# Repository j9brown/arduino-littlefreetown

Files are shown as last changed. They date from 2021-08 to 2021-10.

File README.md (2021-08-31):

# arduino-littlefreetown

Lighting controller for a two story combination Little Free Museum
and Little Free Library structure.

## Parts

PJRC Teensy 3.2 microcontroller
- https://www.pjrc.com/store/teensy32.html

FYSETC v2.1 LCD panel
- https://wiki.fysetc.com/Mini12864_Panel/
- https://github.com/FYSETC/FYSETC-Mini-12864-Panel
- https://www.amazon.com/FYSETC-Controller-Supports-Accessories-RGB-Backlight/dp/B08R9ZH7S2/

Adafruit bq24074 solar charger
- https://www.adafruit.com/product/4755

Adafruit 6 Volt 2 Watt solar panel

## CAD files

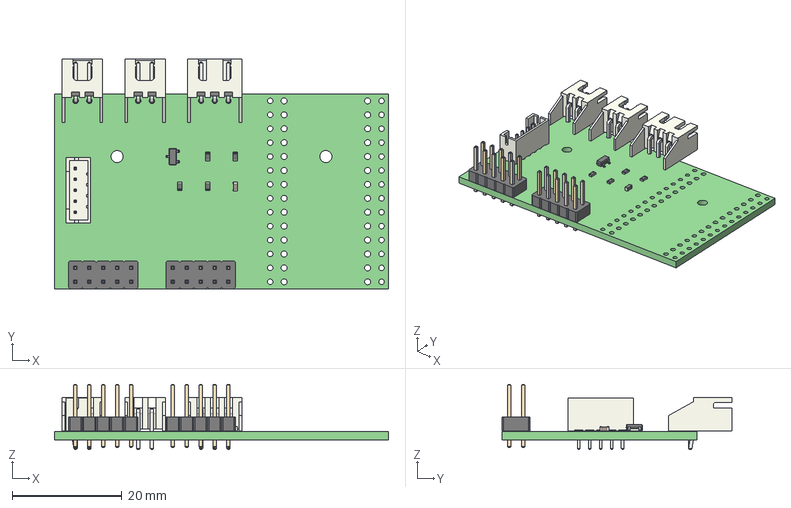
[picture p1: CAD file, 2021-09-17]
board/town.step
61.0 x 41.9 x 11.9 mm

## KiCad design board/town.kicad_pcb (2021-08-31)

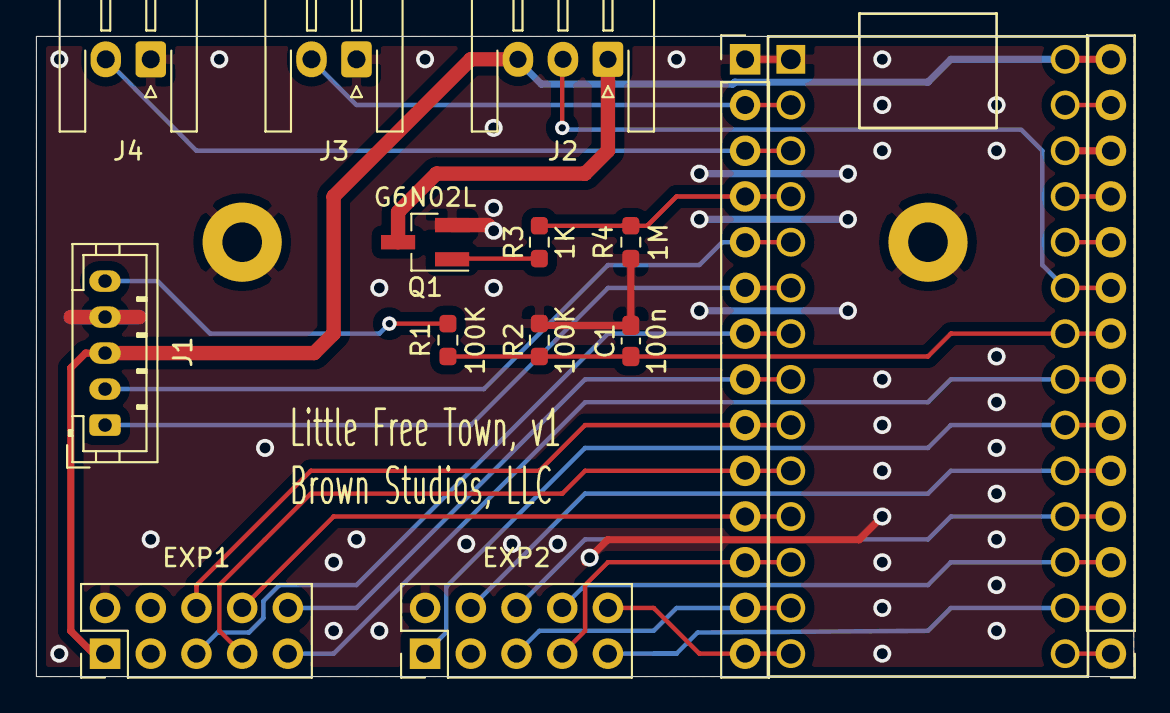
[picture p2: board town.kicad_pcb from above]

Board: 2 copper layers, 61.0 x 35.6 mm, 17 parts (0 on the bottom side), 31 nets.

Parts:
C1: 100n; C_0603_1608Metric_Pad1.08x0.95mm_HandSolder
EXP1, EXP2: Panel Connector; PinHeader_2x05_P2.54mm_Vertical
H1, H2: Header; PinHeader_1x14_P2.54mm_Vertical
J1: Charger Connector; JST_PH_B5B-PH-K_1x05_P2.00mm_Vertical
J2: LED Strip Connector; JST_XH_S3B-XH-A-1_1x03_P2.50mm_Horizontal
J3, J4: Door Sensor; JST_XH_S2B-XH-A-1_1x02_P2.50mm_Horizontal
M1, M2: MountingHole_2.2mm_M2_Pad
Q1: G6N02L; SOT-23_Handsoldering
R1, R2: 100K; R_0603_1608Metric_Pad0.98x0.95mm_HandSolder
R3: 1K; R_0603_1608Metric_Pad0.98x0.95mm_HandSolder
R4: 1M; R_0603_1608Metric_Pad0.98x0.95mm_HandSolder
U1: Teensy3.2; Teensy32_HeadersOnly

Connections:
/AGND: H2.13, U1.32
/BATTMON: C1.1, H2.8, R1.2, R2.1, U1.27
/BEEP: EXP1.10, H1.8, U1.8
/BTN_EN1: EXP2.8, H2.3, U1.22
/BTN_EN2: EXP2.6, H2.4, U1.23
/BTN_ENC: EXP1.9, H2.7, U1.26
/CHG: H1.5, J1.2, U1.5
/DOOR1: H1.2, J3.2, U1.2
/DOOR2: H1.3, J4.2, U1.3
/LCD_A0: EXP1.7, H1.10, U1.10
/LCD_CS: EXP1.8, H1.11, U1.11
/LCD_RST: EXP1.6, H1.9, U1.9
/MISO: EXP2.10, H1.14, U1.14
/MOSI: EXP2.5, H1.13, U1.13
/PANEL_LED_DIN: EXP1.5, H1.7, U1.7
/PGOOD: H1.6, J1.1, U1.6
/SCK: EXP2.9, H2.2, U1.21
/SDCARD_CD: EXP2.4, H2.5, U1.24
/SDCARD_CS: EXP2.7, H1.12, U1.12
/STRIP_LED_DIN: H2.9, J2.2, U1.28
/STRIP_LED_EN: H1.4, R3.2, R4.1, U1.4
/STRIP_LED_GND: J2.1, Q1.3
/SW_KILL: EXP2.1, H2.6, U1.25
/VCC: H2.12, U1.31
/VLIPO: J1.5, R1.1
/X_A8: H2.10, U1.29
/X_A9: H2.11, U1.30
/X_D13: H2.1, U1.20
GND: C1.2, EXP1.2, EXP2.2, H1.1, J1.4, J3.1, J4.1, M1.1, M2.1, Q1.2, R2.2, R4.2, U1.1
unnamed: Q1.1, R3.1
VBUS: EXP1.1, H2.14, J1.3, J2.3, U1.33

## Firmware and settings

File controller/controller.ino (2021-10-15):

/*
 * Required libraries:
 *
 * - Snooze
 *
 * Wiring:
 * - see panel.h
 * - pin 0: DOOR1
 * - pin 1: DOOR2
 * - pin 2: STRIP_LED_EN
 * - pin 3: CHG
 * - pin 4: PGOOD
 * - pin 20/A6: BATTMON
 *           100 K resistor to Vbat
 *           100 K resistor to GND
 *           100 nF capacitor to GND
 * - pin 21: STRIP_LED_DIN
 * - cut trace between Vin and USB if using battery
 */

#include <algorithm>
#include <memory>

#include <Adafruit_NeoPixel.h>
#include <avdweb_Switch.h>
#include <Snooze.h>
#include <SnoozeBlock.h>
#include <Print.h>
#include <TimeLib.h>

#include "battery.h"
#include "panel.h"
#include "settings.h"
#include "ui.h"
#include "utils.h"

#define USE_BUILTIN_LED 0

enum class StrandTestPattern : uint8_t {
  DISABLED, WHITE, GLOW, RAINBOW
};

template <>
struct ChoiceTraits<StrandTestPattern> {
  static constexpr StrandTestPattern min = StrandTestPattern::DISABLED;
  static constexpr StrandTestPattern max = StrandTestPattern::RAINBOW;
  
  static const char* toString(StrandTestPattern value) {
    switch (value) {
      default:
      case StrandTestPattern::DISABLED: return "Disabled";
      case StrandTestPattern::WHITE: return "White";
      case StrandTestPattern::GLOW: return "Glow";
      case StrandTestPattern::RAINBOW: return "Rainbow";
    }
  }
};

enum class OnOff : uint8_t {
  OFF, ON
};

template <>
struct ChoiceTraits<OnOff> {
  static constexpr OnOff min = OnOff::OFF;
  static constexpr OnOff max = OnOff::ON;
  
  static const char* toString(OnOff value) {
    switch (value) {
      default:
      case OnOff::OFF: return "Off";
      case OnOff::ON: return "On";
    }
  }
};

enum class LowBattery : uint8_t {
  DISABLED, V3_3, V3_4, V3_5, V3_6
};

template <>
struct ChoiceTraits<LowBattery> {
  static constexpr LowBattery min = LowBattery::DISABLED;
  static constexpr LowBattery max = LowBattery::V3_6;
  
  static const char* toString(LowBattery value) {
    switch (value) {
      default:
      case LowBattery::DISABLED: return "Disabled";
      case LowBattery::V3_3: return "3.3 V";
      case LowBattery::V3_4: return "3.4 V";
      case LowBattery::V3_5: return "3.5 V";
      case LowBattery::V3_6: return "3.6 V";
    }
  }
};

enum class LightState {
  OFF, ON, ANIMATING
};

LightState mergeLightState(LightState a, LightState b) {
  if (a == LightState::ANIMATING || b == LightState::ANIMATING)
      return LightState::ANIMATING;
  if (a == LightState::ON || b == LightState::ON)
      return LightState::ON;
  return LightState::OFF;
}

namespace {
const uint32_t SETTINGS_SCHEMA_VERSION = 2;
Setting<uint8_t> activityTimeoutSeconds(0);
Setting<uint8_t> dawnHour(1);
Setting<uint8_t> duskHour(2);
Setting<uint8_t> nightHour(3);
Setting<OnOff> lightsOn(7);
Setting<LowBattery> lowBatteryCutoff(8);
Setting<OnOff> sleepOn(9);
Setting<tint_t> museumLightTint(100);
Setting<tone_t> museumLightTone(101);
Setting<brightness_t> museumLightBrightnessDaytime(102);
Setting<brightness_t> museumLightBrightnessEvening(103);
Setting<brightness_t> museumLightBrightnessNighttime(104);
Setting<tint_t> libraryLightTint(200);
Setting<tone_t> libraryLightTone(201);
Setting<brightness_t> libraryLightBrightnessDaytime(202);
Setting<brightness_t> libraryLightBrightnessEvening(203);
Setting<brightness_t> libraryLightBrightnessNighttime(204);
Setting<brightness_t> libraryLightBrightnessWhenOpen(205);
BatteryHistory::Storage batteryHistoryStorage(1000);
Setting<uint8_t> testSetting1(2000);
Setting<int8_t> testSetting2(2001);
Setting<StrandTestPattern> strandTestPattern(2002);

void resetSettings() {
  activityTimeoutSeconds.set(30);
  dawnHour.set(7);
  duskHour.set(18);
  nightHour.set(23);
  lightsOn.set(OnOff::ON);
  lowBatteryCutoff.set(LowBattery::V3_4);
  sleepOn.set(OnOff::ON);
  museumLightTint.set(TINT_WHITE);
  museumLightTone.set(TONE_DEFAULT);
  museumLightBrightnessDaytime.set(BRIGHTNESS_OFF);
  museumLightBrightnessEvening.set(BRIGHTNESS_MAX);
  museumLightBrightnessNighttime.set(BRIGHTNESS_MIN);
  libraryLightTint.set(TINT_WHITE);
  libraryLightTone.set(TONE_DEFAULT);
  libraryLightBrightnessDaytime.set(BRIGHTNESS_OFF);
  libraryLightBrightnessEvening.set(BRIGHTNESS_MAX);
  libraryLightBrightnessNighttime.set(BRIGHTNESS_MIN);
  libraryLightBrightnessWhenOpen.set(BRIGHTNESS_MAX);
  testSetting1.set(0);
  testSetting2.set(0);
  strandTestPattern.set(StrandTestPattern::DISABLED);
}

Settings settings;

Panel panel;
Binding binding(&panel);
Stage stage(&binding,
  [] { return activityTimeoutSeconds.get() * 1000UL; });

constexpr int VBAT_PIN = A6;
constexpr int CHG_PIN = 3;
constexpr int PGOOD_PIN = 4;

Battery battery(VBAT_PIN);
BatteryHistory batteryHistory(&battery, batteryHistoryStorage);
LowBatteryDetector lowBatteryDetector(&battery, []() -> millivolt_t {
  switch (lowBatteryCutoff.get()) {
    default:
    case LowBattery::DISABLED:
      return 0;
    case LowBattery::V3_3:
      return 3300;
    case LowBattery::V3_4:
      return 3400;
    case LowBattery::V3_5:
      return 3500;
    case LowBattery::V3_6:
      return 3600;
  }
});

constexpr int LIGHTS_EN_PIN = 2;
constexpr int LIGHTS_PIN = 21;
constexpr unsigned LIGHTS_MUSEUM_FIRST = 0;
constexpr unsigned LIGHTS_MUSEUM_COUNT = 11;
constexpr unsigned LIGHTS_LIBRARY_FIRST = 11;
constexpr unsigned LIGHTS_LIBRARY_COUNT = 11;
constexpr unsigned LIGHTS_TOTAL_COUNT = 22;
Adafruit_NeoPixel lights(LIGHTS_TOTAL_COUNT, LIGHTS_PIN, NEO_GRBW | NEO_KHZ800);
RGBW oldLights[LIGHTS_TOTAL_COUNT];
RGBW newLights[LIGHTS_TOTAL_COUNT];
bool oldLightsEnabled;

constexpr int MUSEUM_DOOR_PIN = 0;
constexpr int LIBRARY_DOOR_PIN = 1;

Switch museumDoor(MUSEUM_DOOR_PIN, INPUT_PULLUP);
Switch libraryDoor(LIBRARY_DOOR_PIN, INPUT_PULLUP);

SnoozeDigital snoozeDigital;
SnoozeUSBSerial snoozeUsbSerial;
SnoozeTimer snoozeTimer;
SnoozeBlock snoozeBlock(snoozeUsbSerial, snoozeDigital, snoozeTimer);

enum class TimeOfDay {
  NIGHTTIME,
  DAYTIME,
  EVENING
};

TimeOfDay timeOfDay() {
  uint8_t h = hour();
  if (h < dawnHour.get()) {
    if (nightHour.get() < dawnHour.get() && h < nightHour.get()) {
      return TimeOfDay::EVENING;
    }
    return TimeOfDay::NIGHTTIME;
  }
  if (h < duskHour.get()) {
    return TimeOfDay::DAYTIME;
  }
  if (h < nightHour.get()) {
    return TimeOfDay::EVENING;
  }
  return TimeOfDay::NIGHTTIME;
}
} // namespace

template <typename Fn>
void editTime(Fn fn) {
  time_t time = now();
  TimeElements te;
  breakTime(time, te);
  fn(&te);
  time = makeTime(te);
  Teensy3Clock.set(time);
  setTime(time);
}

void clampDayOfMonth(TimeElements* te, bool rollover) {
  while (day(makeTime(*te)) != te->Day) {
    te->Day = rollover ? 1 : te->Day - 1;
  }
}

std::unique_ptr<Menu> makeMuseumMenu() {
  auto menu = std::make_unique<Menu>();
  menu->addItem(std::make_unique<TitleItem>("MUSEUM"));
  menu->addItem(std::make_unique<TintItem>("Tint", museumLightTint));
  menu->addItem(std::make_unique<ToneItem>("Tone", museumLightTint, museumLightTone));
  menu->addItem(std::make_unique<BrightnessItem>("Brightness: Day", museumLightBrightnessDaytime));
  menu->addItem(std::make_unique<BrightnessItem>("Brightness: Evening", museumLightBrightnessEvening));
  menu->addItem(std::make_unique<BrightnessItem>("Brightness: Night", museumLightBrightnessNighttime));
  return menu;
}

std::unique_ptr<Menu> makeLibraryMenu() {
  auto menu = std::make_unique<Menu>();
  menu->addItem(std::make_unique<TitleItem>("LIBRARY"));
  menu->addItem(std::make_unique<TintItem>("Tint", libraryLightTint));
  menu->addItem(std::make_unique<ToneItem>("Tone", libraryLightTint, libraryLightTone));
  menu->addItem(std::make_unique<BrightnessItem>("Brightness: Day", libraryLightBrightnessDaytime));
  menu->addItem(std::make_unique<BrightnessItem>("Brightness: Evening", libraryLightBrightnessEvening));
  menu->addItem(std::make_unique<BrightnessItem>("Brightness: Night", libraryLightBrightnessNighttime));
  menu->addItem(std::make_unique<BrightnessItem>("Brightness: Door Open", libraryLightBrightnessWhenOpen));
  return menu;
}

std::unique_ptr<Menu> makeTimeMenu() {
  auto menu = std::make_unique<Menu>();
  menu->addItem(std::make_unique<TitleItem>("TIME"));
  menu->addItem(std::make_unique<NumericItem<int>>("Year", Editable<int>(
    [] { return year(); },
    [] (int x) {
      editTime([x] (TimeElements* te) {
        te->Year = CalendarYrToTm(x);
        clampDayOfMonth(te, false);
      });
    }),
    2021, 2037, 1));
  menu->addItem(std::make_unique<NumericItem<int>>("Month", Editable<int>(
    [] { return month(); },
    [] (int x) {
      editTime([x] (TimeElements* te) {
        te->Month = x;
        clampDayOfMonth(te, false);
      });
    }),
    1, 12, 1));
  menu->addItem(std::make_unique<NumericItem<int>>("Day", Editable<int>(
    [] { return day(); },
    [] (int x) {
      editTime([x] (TimeElements* te) {
        bool rollover = x > te->Day;
        te->Day = x;
        clampDayOfMonth(te, rollover);
      });
    }),
    1, 31, 1));
  menu->addItem(std::make_unique<NumericItem<int>>("Hour", Editable<int>(
    [] { return hour(); },
    [] (int x) {
      editTime([x] (TimeElements* te) { te->Hour = x; });
    }),
    0, 23, 1));
  menu->addItem(std::make_unique<NumericItem<int>>("Minute", Editable<int>(
    [] { return minute(); },
    [] (int x) {
      editTime([x] (TimeElements* te) { te->Minute = x; });
    }),
    0, 59, 1));
  menu->addItem(std::make_unique<NumericItem<int>>("Second", Editable<int>(
    [] { return second(); },
    [] (int x) {
      editTime([x] (TimeElements* te) { te->Second = x; });
    }),
    0, 59, 1));
  return menu;
}

std::unique_ptr<Menu> makePowerSavingMenu() {
  auto menu = std::make_unique<Menu>();
  menu->addItem(std::make_unique<TitleItem>("POWER"));
  menu->addItem(std::make_unique<ChoiceItem<OnOff>>("Lights", lightsOn));
  menu->addItem(std::make_unique<NumericItem<uint8_t>>("Dawn Hour",
    dawnHour, 0, 23, 1));
  menu->addItem(std::make_unique<NumericItem<uint8_t>>("Dusk Hour",
    duskHour, 0, 23, 1));
  menu->addItem(std::make_unique<NumericItem<uint8_t>>("Night Hour",
    nightHour, 0, 23, 1));
  menu->addItem(std::make_unique<NumericItem<uint8_t>>("Display Timeout (s)",
    activityTimeoutSeconds, 0, 240, 10));
  menu->addItem(std::make_unique<ChoiceItem<LowBattery>>("Low Battery Cutoff", lowBatteryCutoff));
  menu->addItem(std::make_unique<ChoiceItem<OnOff>>("Sleep When Idle", sleepOn));
  return menu;
}

class BatteryMonitor : public Scene {
public:
  BatteryMonitor() {}
  virtual ~BatteryMonitor() override {}

  void poll(Context& context) override;
  void draw(Context& context, Canvas& canvas) override;
  bool input(Context& context, const InputEvent& event) override;

private:
  static constexpr uint32_t DISPLAY_WIDTH = 128;
  static constexpr uint32_t DISPLAY_HEIGHT = 64;
  static constexpr uint32_t CHART_WIDTH = 100;
  static constexpr uint32_t CHART_HEIGHT = 36;
  static constexpr uint32_t CHART_X = DISPLAY_WIDTH - CHART_WIDTH - 1;
  static constexpr uint32_t CHART_Y = DISPLAY_HEIGHT - CHART_HEIGHT - 11;
  static constexpr int32_t SCROLL_SPEED = 8;
  static constexpr uint32_t SCROLL_MIN = 0;
  static constexpr uint32_t SCROLL_MAX = BatteryHistory::LENGTH - CHART_WIDTH;
  static constexpr float VOLTAGE_MIN = 3.2f;
  static constexpr float VOLTAGE_MAX = 4.2f;
  static constexpr uint32_t DIVISION_MINOR = (60 * 60) / BatteryHistory::INTERVAL; // every hour
  static constexpr uint32_t DIVISION_MAJOR = DIVISION_MINOR * 12;

  enum class State {
    DISCHARGING, CHARGING, POWERED
  };

  time_t _time = 0;
  millivolt_t _voltage = 0;
  uint32_t _scroll = SCROLL_MAX;
  State _state = State::DISCHARGING;
};

void BatteryMonitor::poll(Context& context) {
  time_t t = now();
  if (t != _time) {
    _time = t;
    _voltage = battery.read();
    context.requestDraw();
  }

  State newState = State::DISCHARGING;
  if (!digitalRead(CHG_PIN)) {
    newState = State::CHARGING;
  } else if (!digitalRead(PGOOD_PIN)) {
    newState = State::POWERED;
  }
  if (newState != _state) {
    _state = newState;
    context.requestDraw();
  }
}

void BatteryMonitor::draw(Context& context, Canvas& canvas) {
  canvas.gfx().setCursor(1, 0);
  canvas.gfx().setFont(TITLE_FONT);
  canvas.gfx().print("BATTERY: ");
  canvas.gfx().print(_voltage * 0.001f, 2);
  canvas.gfx().print(" V ");

  canvas.gfx().setFont(u8g2_font_open_iconic_embedded_1x_t);
  switch (_state) {
    case State::CHARGING:
      canvas.gfx().drawStr(109, 1, "C");
      break;
    case State::POWERED:
      canvas.gfx().drawStr(109, 1, "B");
      break;
    default:
      break;
  }
  canvas.gfx().drawStr(118, 1, _voltage < 3500 ? "@" : "I");

  // Draw the Y axis and labels
  canvas.gfx().setFont(u8g2_font_4x6_tr);
  canvas.gfx().drawLine(CHART_X - 1, CHART_Y, CHART_X - 1, CHART_Y + CHART_HEIGHT - 1);
  canvas.gfx().drawStr(2, CHART_Y - 3, "4.2 V");
  canvas.gfx().drawLine(CHART_X - 4, CHART_Y, CHART_X - 2, CHART_Y);
  uint32_t v37elev = (3.7 - VOLTAGE_MIN) * CHART_HEIGHT / (VOLTAGE_MAX - VOLTAGE_MIN);
  canvas.gfx().drawStr(2, CHART_Y + CHART_HEIGHT - 1 - v37elev - 3, "3.7 V");
  canvas.gfx().drawLine(CHART_X - 4, CHART_Y + CHART_HEIGHT - 1 - v37elev, CHART_X - 2, CHART_Y + CHART_HEIGHT - 1 - v37elev);
  canvas.gfx().drawStr(2, CHART_Y + CHART_HEIGHT - 1 - 3, "3.2 V");
  canvas.gfx().drawLine(CHART_X - 4, CHART_Y + CHART_HEIGHT - 1, CHART_X - 2, CHART_Y + CHART_HEIGHT - 1);

  // Draw the chart and X axis labels
  uint32_t currentPeriod = batteryHistory.currentPeriod();
  for (uint32_t pos = 0; pos < CHART_WIDTH; pos++) {
    uint32_t index = pos + _scroll;
    uint32_t period = (index + currentPeriod + 1) % BatteryHistory::LENGTH;
    float voltage = std::min(std::max(batteryHistory.getAt(period) * 0.001f, VOLTAGE_MIN), VOLTAGE_MAX);
    uint32_t elev = (voltage - VOLTAGE_MIN) * CHART_HEIGHT / (VOLTAGE_MAX - VOLTAGE_MIN);
    uint32_t x = pos + CHART_X;
    canvas.gfx().drawBox(x, CHART_Y + CHART_HEIGHT - 1 - elev, 1, elev + 1);

    uint32_t age = BatteryHistory::LENGTH - index - 1;
    if ((age % DIVISION_MAJOR) == 0) {
      canvas.gfx().drawLine(x, CHART_Y + CHART_HEIGHT, x, CHART_Y + CHART_HEIGHT + 3);
      String text;
      text.append(age / DIVISION_MINOR);
      text.append('h');
      canvas.gfx().drawStr(x - canvas.gfx().getStrWidth(text.c_str()) + 1, CHART_Y + CHART_HEIGHT + 4, text.c_str());
    } else if ((age % DIVISION_MINOR) == 0) {
      canvas.gfx().drawLine(x, CHART_Y + CHART_HEIGHT, x, CHART_Y + CHART_HEIGHT + 1);
    }
  }
}

bool BatteryMonitor::input(Context& context, const InputEvent& event) {
  switch (event.type) {
    case InputType::ROTATE:
      _scroll = std::min(std::max(int32_t(_scroll) + event.value * SCROLL_SPEED,
          int32_t(SCROLL_MIN)), int32_t(SCROLL_MAX));
      context.requestDraw();
      return true;
    default:
      return false;
  }
}

std::unique_ptr<BatteryMonitor> makeBatteryMonitorScene() {
  return std::make_unique<BatteryMonitor>();
}

class BoardTest : public Scene {
public:
  BoardTest() {}
  virtual ~BoardTest() override {}

  void poll(Context& context) override;
  void draw(Context& context, Canvas& canvas) override;
  bool input(Context& context, const InputEvent& event) override;

private:
  String _message = "---";
  uint8_t _index = 0;
  uint8_t _values[2] = { 200, 40 };
  time_t _time = 0;
};

void BoardTest::poll(Context& context) {
  time_t t = now();
  if (t != _time) {
    _time = t;
    context.requestDraw();
  }
  if (museumDoor.switched() || libraryDoor.switched()) {
    context.requestDraw();
  }
}

bool BoardTest::input(Context& context, const InputEvent& event) {
  switch (event.type) {
    case InputType::LONG_PRESS:
      _message = "LONG_PRESS";
      context.requestSleep();
      break;
    case InputType::SINGLE_CLICK:
      _message = "SINGLE_CLICK";
      _index = _index ? 0 : 1;
      break;
    case InputType::DOUBLE_CLICK:
      _message = "DOUBLE_CLICK";
      break;
    case InputType::ROTATE:
      _message = "ROTATE " + String(event.value);
      _values[_index] += uint8_t(event.value * 5);
      break;
    case InputType::BACK:
      _message = "BACK";
      break;
    case InputType::HOME:
      _message = "HOME";
      break;
    default:
      break;
  }

  context.requestDraw();
  return false;
}

void BoardTest::draw(Context& context, Canvas& canvas) {
  canvas.gfx().setFont(TITLE_FONT);
  canvas.gfx().drawStr(1, 0, "BOARD TEST");
  canvas.gfx().setFont(DEFAULT_FONT);

  canvas.gfx().setCursor(1, 10);
  canvas.gfx().print("Input: ");
  canvas.gfx().print(_message.c_str());

  canvas.gfx().setCursor(1, 20);
  canvas.gfx().print("Museum door: ");
  canvas.gfx().print(museumDoor.on() ? "Closed" : "Open");

  canvas.gfx().setCursor(1, 30);
  canvas.gfx().print("Library door: ");
  canvas.gfx().print(libraryDoor.on() ? "Closed" : "Open");

  canvas.gfx().setCursor(1, 40);
  canvas.gfx().print("Time: ");
  printDateAndTime(canvas.gfx(), _time);

  canvas.gfx().setCursor(1, 50);
  canvas.gfx().print("Time of Day: ");
  switch (timeOfDay()) {
    case TimeOfDay::DAYTIME:
      canvas.gfx().print("Daytime");
      break;
    case TimeOfDay::EVENING:
      canvas.gfx().print("Evening");
      break;
    case TimeOfDay::NIGHTTIME:
      canvas.gfx().print("Nighttime");
      break;
  }

  canvas.setDisplayColor(RGB::colorWheel(_values[0]) * 0.8f);
  canvas.setKnobColor(RGB::colorWheel(_values[1]) * 0.4f);
}

std::unique_ptr<BoardTest> makeBoardTestScene() {
  return std::make_unique<BoardTest>();
}

std::unique_ptr<Menu> makeEepromTestMenu() {
  auto menu = std::make_unique<Menu>();
  menu->addItem(std::make_unique<TitleItem>("EEPROM TEST"));
  menu->addItem(std::make_unique<NumericItem<uint8_t>>("Test Setting 1",
    testSetting1, 0, 100, 5));
  menu->addItem(std::make_unique<NumericItem<int8_t>>("Test Setting 2",
    testSetting2, -10, 10, 1));
  return menu;
}

std::unique_ptr<Menu> makeStrandTestMenu() {
  auto menu = std::make_unique<Menu>();
  menu->addItem(std::make_unique<TitleItem>("STRAND TEST"));
  menu->addItem(std::make_unique<ChoiceItem<StrandTestPattern>>("Pattern", strandTestPattern));
  return menu;
}

std::unique_ptr<Menu> makeFactoryResetMenu() {
  auto menu = std::make_unique<Menu>();
  menu->addItem(std::make_unique<TitleItem>("FACTORY RESET"));
  menu->addItem(std::make_unique<BackItem>("Back Away Slowly..."));
  menu->addItem(std::make_unique<NavigateItem>("Erase All Settings!", Settings::eraseAndReboot));
  return menu;
}

std::unique_ptr<Menu> makeDiagnosticsMenu() {
  auto menu = std::make_unique<Menu>();
  menu->addItem(std::make_unique<TitleItem>("DIAGNOSTICS"));
  menu->addItem(std::make_unique<NavigateItem>("Board Test", makeBoardTestScene));
  menu->addItem(std::make_unique<NavigateItem>("Strand Test", makeStrandTestMenu));
  menu->addItem(std::make_unique<NavigateItem>("EEPROM Test", makeEepromTestMenu));
  menu->addItem(std::make_unique<NavigateItem>("Factory Reset", makeFactoryResetMenu));
  return menu;
}

std::unique_ptr<Menu> makeRootMenu() {
  auto menu = std::make_unique<Menu>();
  menu->addItem(std::make_unique<TitleItem>("LITTLE FREE TOWN"));
  menu->addItem(std::make_unique<NavigateItem>("Museum", makeMuseumMenu));
  menu->addItem(std::make_unique<NavigateItem>("Library", makeLibraryMenu));
  menu->addItem(std::make_unique<NavigateItem>("Time", makeTimeMenu));
  menu->addItem(std::make_unique<NavigateItem>("Power Saving", makePowerSavingMenu));
  menu->addItem(std::make_unique<NavigateItem>("Battery Monitor", makeBatteryMonitorScene));
  menu->addItem(std::make_unique<NavigateItem>("Diagnostics", makeDiagnosticsMenu));
  return menu;
}

brightness_t museumLightBrightness() {
  switch (timeOfDay()) {
    case TimeOfDay::DAYTIME:
      return museumLightBrightnessDaytime.get();
    case TimeOfDay::EVENING:
      return museumLightBrightnessEvening.get();
    case TimeOfDay::NIGHTTIME:
      return museumLightBrightnessNighttime.get();
  }
  return BRIGHTNESS_OFF;
}

LightState renderMuseumLights() {
  brightness_t brightness = museumLightBrightness();
  if (brightness == BRIGHTNESS_OFF) return LightState::OFF;
  
  RGBW color = makeStripColor(museumLightTint.get(), museumLightTone.get(), brightness);
  for (size_t i = 0; i < LIGHTS_MUSEUM_COUNT; i++) {
    newLights[i + LIGHTS_MUSEUM_FIRST] = color;
  }
  return LightState::ON;
}

brightness_t libraryLightBrightness() {
  if (!libraryDoor.on()) {
    return libraryLightBrightnessWhenOpen.get();
  }
  switch (timeOfDay()) {
    case TimeOfDay::DAYTIME:
      return libraryLightBrightnessDaytime.get();
    case TimeOfDay::EVENING:
      return libraryLightBrightnessEvening.get();
    case TimeOfDay::NIGHTTIME:
      return libraryLightBrightnessNighttime.get();
  }
  return BRIGHTNESS_OFF;
}

LightState renderLibraryLights() {
  brightness_t brightness = libraryLightBrightness();
  if (brightness == BRIGHTNESS_OFF) return LightState::OFF;

  RGBW color = makeStripColor(libraryLightTint.get(), libraryLightTone.get(), brightness);
  for (size_t i = 0; i < LIGHTS_LIBRARY_COUNT; i++) {
    newLights[i + LIGHTS_LIBRARY_FIRST] = color;
  }
  return LightState::ON;
}
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
void loop() {
  // Update statistics
  batteryHistory.update();
  
  // Update sensors
  museumDoor.poll();
  libraryDoor.poll();

  // Update user interface and LEDs
  panel.update();
  stage.update();
  LightState state = updateLights();

  // Go to sleep if nothing else going on
  bool canSleep = sleepOn.get() == OnOff::ON && state != LightState::ANIMATING
      && panel.canSleep() && stage.canSleep();
  if (!sleepWhenReady(canSleep)) {
    // Save about 3 mA by throttling the loop a little
    delay(5);
  }
}

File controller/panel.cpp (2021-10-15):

#include <SPI.h>

#include "panel.h"
#include "utils.h"

namespace {
//const u8g2_cb_t* LCD_ROTATION = U8G2_R2;
const u8g2_cb_t* LCD_ROTATION = U8G2_R0;
const int LCD_CS = 9;
const int LCD_A0 = 8;
const int LCD_RST = 7;
const int LCD_MOSI = 11;
const int LCD_MISO = 12;
const int LCD_SCK = 14;

const int LED_DIN = 5;

const int SW_KILL = 18;

const int BEEP = 6;

const int BTN_ENC = 19;
const int BTN_EN1 = 15;
const int BTN_EN2 = 16;
} // namespace

Panel::Panel() :
    _display(LCD_ROTATION, LCD_CS, LCD_A0, LCD_RST),
    _leds(3, LED_DIN, NEO_RGB | NEO_KHZ800),
    _knobEncoder(BTN_EN2, BTN_EN1),
    _knobRotations(0),
    _knobButton(BTN_ENC, INPUT_PULLUP),
    _killButton(SW_KILL, INPUT) {
}

void Panel::begin(SnoozeDigital& snoozeDigital) {
  // Reassign the SPI pins
  SPI.setMOSI(LCD_MOSI);
  SPI.setMISO(LCD_MISO);
  SPI.setSCK(LCD_SCK);

  // Initialize the display
  _display.begin();

  // Initialize the LEDs
  _leds.begin();
  _leds.show();

  // Initialize the rotary encoder
  _knobEncoder.begin();

  // Configure snooze block
  snoozeDigital.pinMode(BTN_ENC, INPUT_PULLUP, CHANGE);
  snoozeDigital.pinMode(SW_KILL, INPUT, CHANGE);
  snoozeDigital.pinMode(BTN_EN1, INPUT_PULLUP, CHANGE);
  snoozeDigital.pinMode(BTN_EN2, INPUT_PULLUP, CHANGE);
}

void Panel::update() {
  updateKnobRotation();
  updateButton(&_knobButton, &_knobButtonEvent);
  updateButton(&_killButton, &_killButtonEvent);
}

void Panel::setColors(RGB display, RGB knob) {
  _leds.setPixelColor(0, display.r, display.g, display.b);
  _leds.setPixelColor(1, knob.r, knob.g, knob.b);
  _leds.setPixelColor(2, knob.r, knob.g, knob.b);
  _leds.show();
}

int32_t Panel::readKnobRotations() {
  int32_t count = _knobRotations;
  _knobRotations = 0;
  return count;
}

void Panel::updateKnobRotation() {
  switch (_knobEncoder.read()) {
    case DIR_CW:
      _knobRotations++;
      break;
    case DIR_CCW:
      _knobRotations--;
      break;
  }
}

Panel::ButtonEvent Panel::readKnobButton() {
  ButtonEvent event = _knobButtonEvent;
  _knobButtonEvent = ButtonEvent::NONE;
  return event;
}

Panel::ButtonEvent Panel::readKillButton() {
  ButtonEvent event = _killButtonEvent;
  _killButtonEvent = ButtonEvent::NONE;
  return event;
}

void Panel::updateButton(Switch* button, ButtonEvent* event) {
  button->poll();
  if (button->doubleClick()) {
    *event = ButtonEvent::DOUBLE_CLICK;
  } else if (button->singleClick()) {
    *event = ButtonEvent::SINGLE_CLICK;
  } else if (button->longPress()) {
    *event = ButtonEvent::LONG_PRESS;
  }
}

void Panel::playTone(uint32_t freq, uint32_t millis) {
  tone(BEEP, freq, millis);
}

bool Panel::canSleep() const {
  return _knobRotations == 0
      && _knobButtonEvent == ButtonEvent::NONE
      && _killButtonEvent == ButtonEvent::NONE
      && digitalRead(BTN_ENC)
      && digitalRead(SW_KILL);
}

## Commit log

2021-07-04 Initial commit of the display and UI framework.
2021-07-08 Added LED strip, more settings, color calculations.
2021-08-04 Add battery monitoring, strand test, and lights off features.
2021-08-05 Add a low battery cutoff.
2021-08-07 Rearrange files to make room for PCB design.
2021-08-31 Add PCB design.
    [town-B_Cu.gbr, town-B_Mask.gbr, town-B_Paste.gbr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]
2021-09-01 Update for new PCB design.
2021-09-01 Add low-power sleep mode.
2021-09-17 Add CAD export.
    [town.step]
2021-09-17 Add support for showing charging state.
2021-09-17 Move battery monitor to main menu.
2021-09-17 Add door sensor support.
2021-09-19 Improve battery monitoring.
    Moved to new file.
    Clear stale data points after the device has been turned off
    for a while.
